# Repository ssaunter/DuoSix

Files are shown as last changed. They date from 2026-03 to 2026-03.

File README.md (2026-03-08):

# DuoSix
DuoSix is a 6-key, dual-encoder macropad powered by a Seeed Studio XIAO RP2040 and a PCF8574N IO Expander. 

Right now, the buttons are just bound to media controls, but I intend to update the code in the future to store "libraries" of key presets based on different apps or uses, which can be navigated and selected through the OLED and one of the encoders.

I made this project to learn how to use some new programs, while challenging myself to make something that I'll want to use for a long time. While I have experience in CAD and some of EDA in fusion, I had zero expereience in KiCad or Github before this project, so figuring everything out over about four days felt great.

---
**DuoSix Full Assembly**

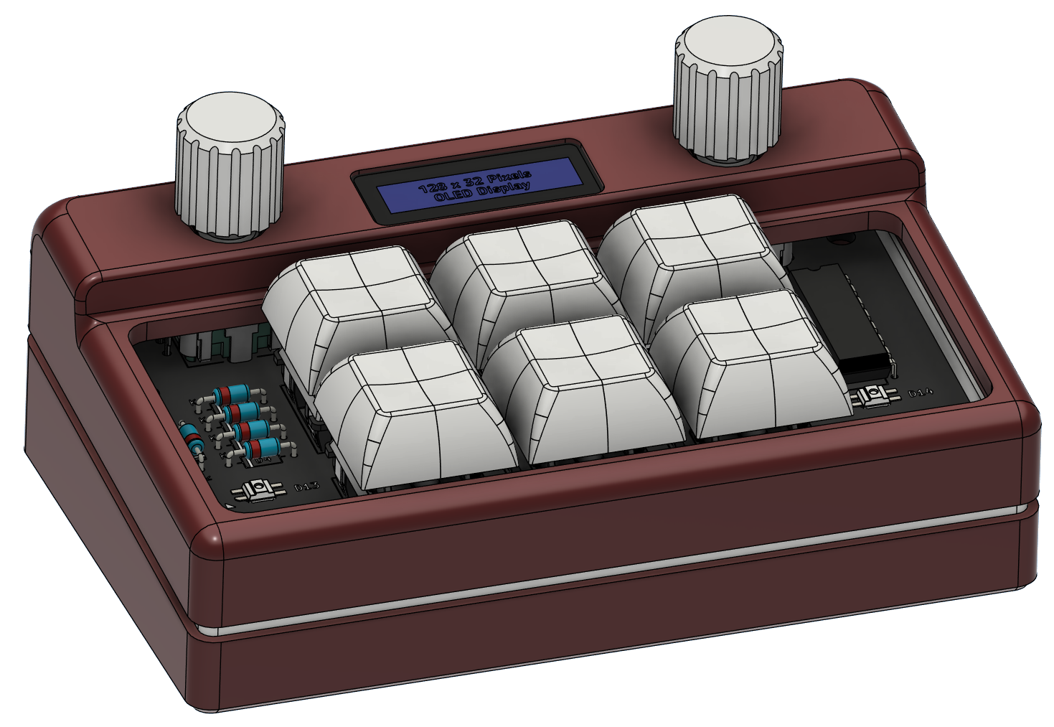
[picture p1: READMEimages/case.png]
Fully Assembly


---

**KiCad Schematic**

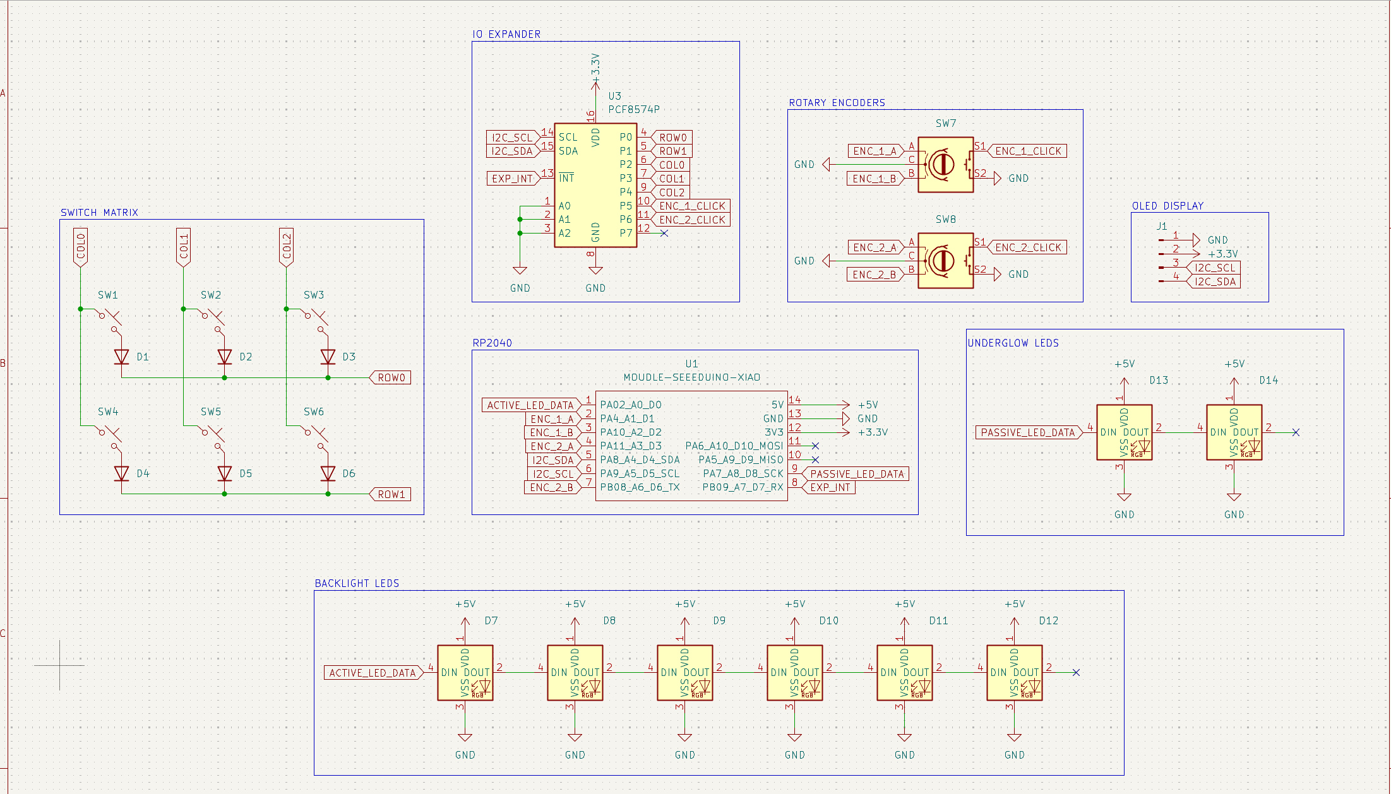
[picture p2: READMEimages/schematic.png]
Circuit schematic


---

**KiCad PCB Routing**

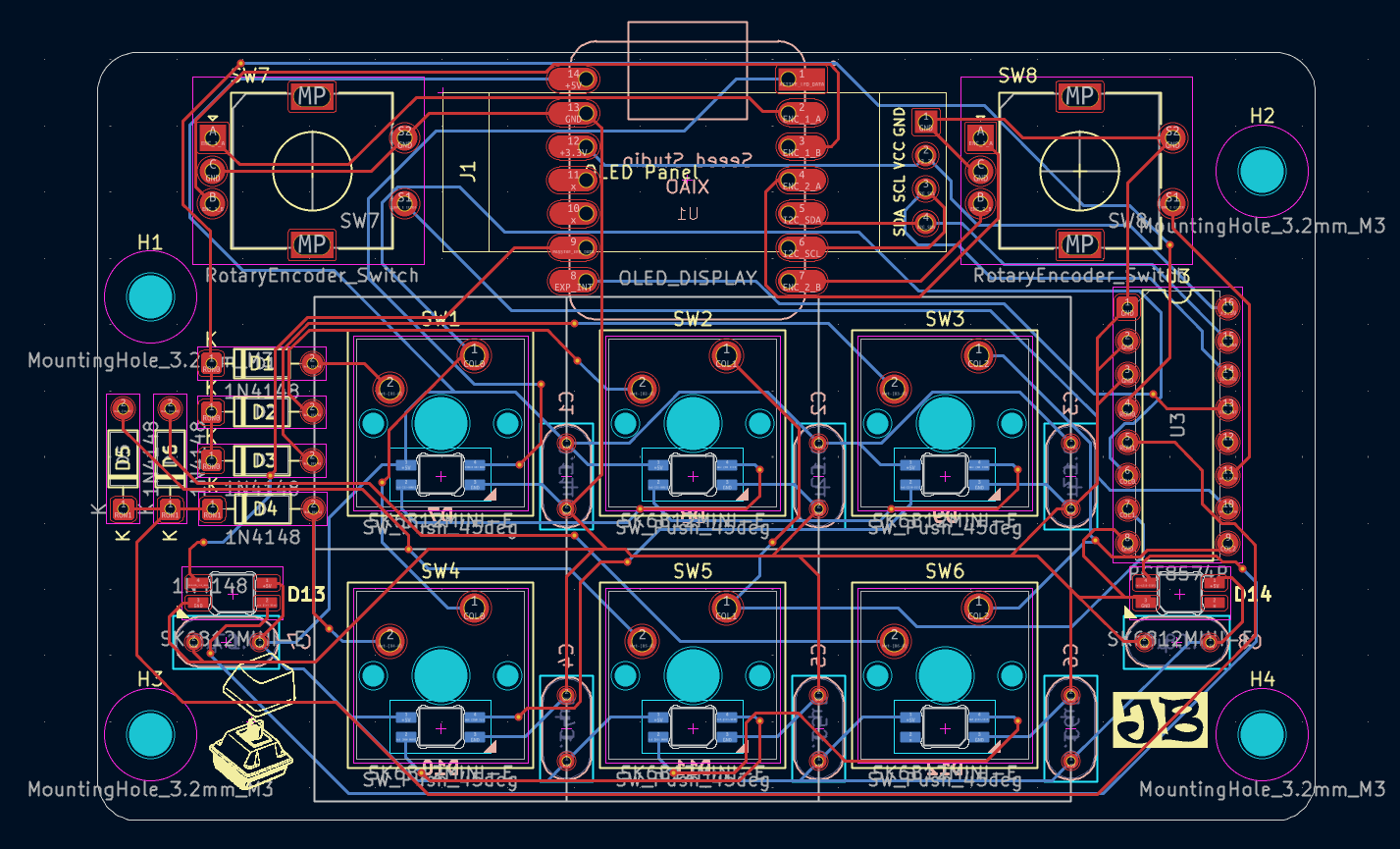
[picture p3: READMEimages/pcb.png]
PCB layout with IO expander


---

**Case and PCB Fitment**

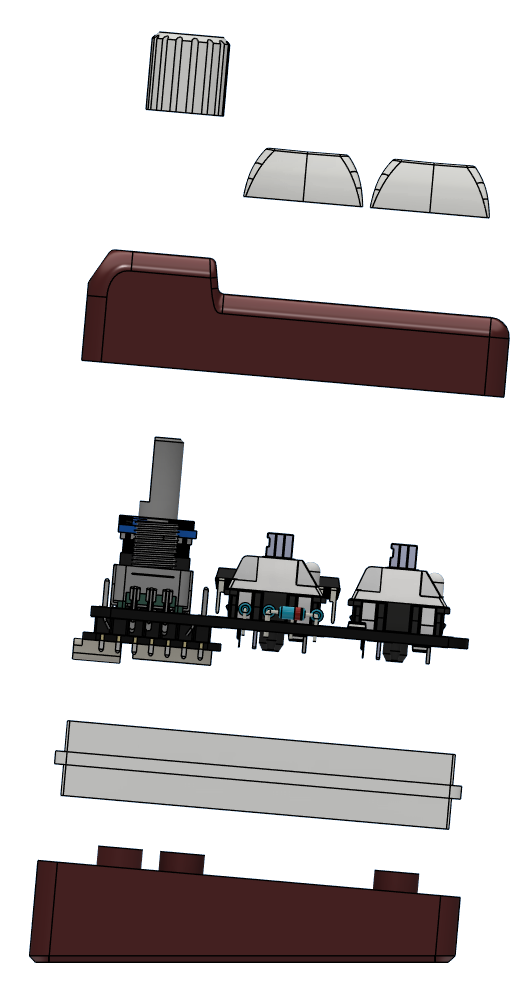
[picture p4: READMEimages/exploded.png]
3D printed case assembly


This design utilizes mostly press-fit connection. The PCB is mounted to the bottom case using M3x6 screws, and the diffusing ring is set in place around it, and in contact with the base. The diffusing ring is then slotted into the top case, holding the case together. I also made knobs to press-fit onto the rotary encoders.

---
### Bill of Materials (BOM)

**Included:**
* 1x Seeed Studio XIAO RP2040
* 6x MX-Style switches
* 6x DSA keycaps
* 2x EC11 rotary encoders
* 1x 0.91 inch OLED display
* 6x 1N4148 diodes
* 8x SK6812 MINI-E LEDs
* 4x M3x5mx4mm heatset inserts
* 3D Printed Case Components (Top, Bottom, Diffuser)

**Self Sourced:**
* 1x PCF8574N IO expander
* 1x 4 pin female socket (raises OLED up)
* 4x M3x6mm screws

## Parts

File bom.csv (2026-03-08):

Part | Quantity | Price | Link | Total
Seeed Studio XIAO RP2040 | 1 | $4.68 | https://www.digikey.com/en/products/detail/seeed-technology-co-ltd/102010428/14672129?gclsrc=aw.ds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 | $4.68
MX-Style Switches | 6 | $5.70 | https://www.digikey.com/en/products/detail/adafruit-industries-llc/5123/14617350?gclsrc=aw.ds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 | $10.38
Rotary Encoders (EC11) | 2 | $1.92 | https://www.digikey.com/en/products/detail/bourns-inc/PEC11R-4015F-N0024/4499636?gclsrc=aw.ds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 | $12.30
1N4148 Diodes | 5 | $0.50 | https://www.digikey.com/en/products/detail/onsemi/1N4148TA/1532747?gclsrc=aw.ds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 | $12.80
0.91 inch OLED | 1 | $7.88 | https://www.digikey.com/en/products/detail/midas-displays/MDOB128032GV-WI/25616500?gclsrc=aw.ds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 | $20.68
DSA Keycaps | 6 | $4.95 | https://www.digikey.com/en/products/detail/adafruit-industries-llc/5039/14313478?gclsrc=aw.ds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 | $25.63
SK6812 MINI-E LEDs | 8 | $2.95 | https://www.digikey.com/en/products/detail/adafruit-industries-llc/4960/14302512?gclsrc=aw.ds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 | $28.58
M3x5mx4mm heatset inserts | 4 | $4.99 | https://www.amazon.com/Aoserge-100Pcs-Brass-Heat-Inserts/dp/B0FM45X5TD | $33.57
PCF8574P IO Expander | 1 | $2.66 | https://www.digikey.com/short/qpvwbhz7 | $36.23
4 Pin Female Header | 1 | $0.37 | https://www.digikey.com/short/jwctq253 | $36.60

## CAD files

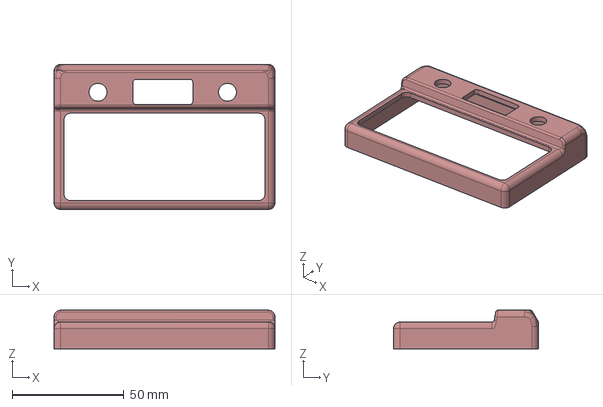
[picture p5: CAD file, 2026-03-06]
production/Top Case.step
99.0 x 65.0 x 17.3 mm

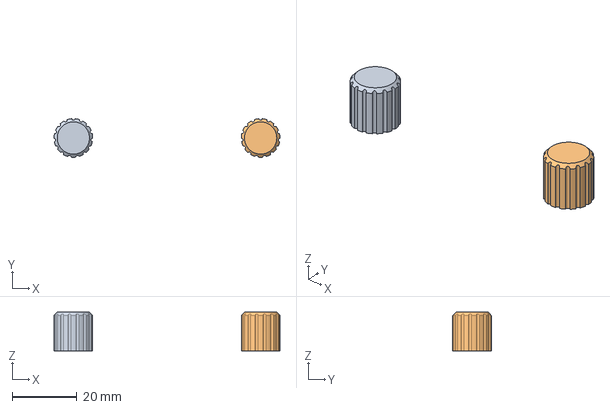
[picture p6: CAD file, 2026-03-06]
production/Knobs.step
70.0 x 12.0 x 12.0 mm

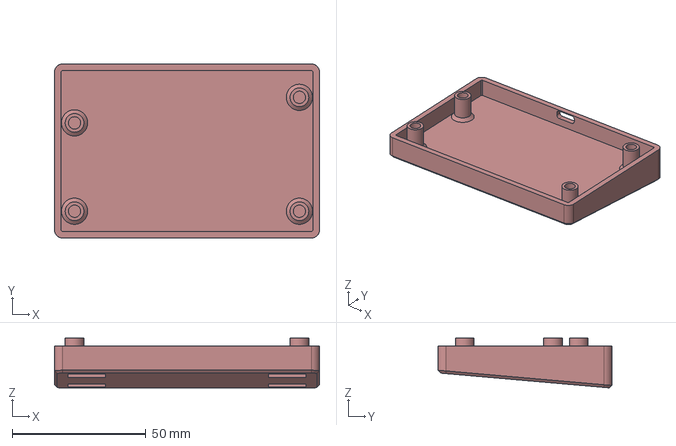
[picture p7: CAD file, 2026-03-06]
production/Bottom Case.step
99.0 x 65.0 x 18.6 mm

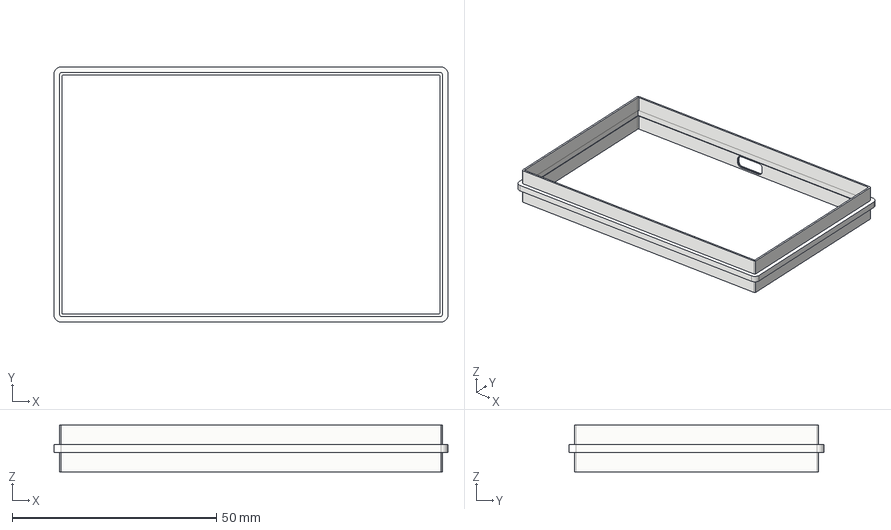
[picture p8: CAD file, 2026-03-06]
production/Diffusion Bar.step
96.5 x 62.5 x 11.5 mm

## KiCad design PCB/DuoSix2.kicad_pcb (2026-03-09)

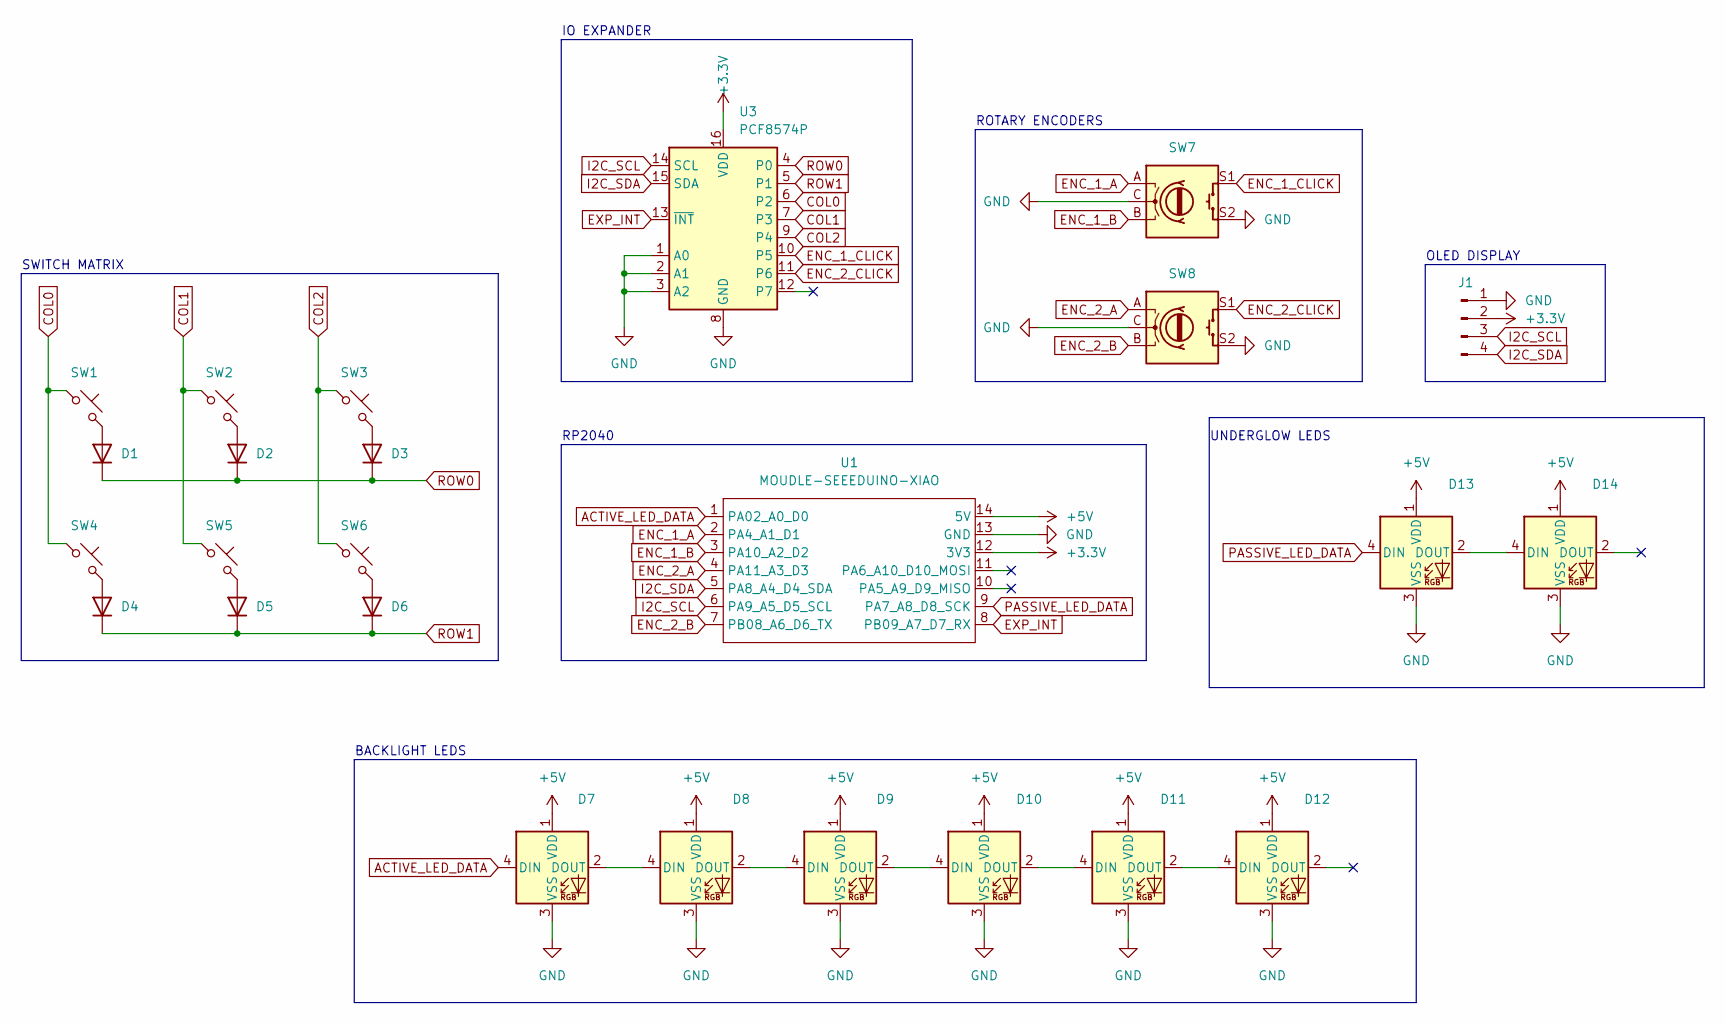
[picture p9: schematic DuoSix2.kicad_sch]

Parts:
D1, D2, D3, D4, D5, D6: 1N4148; D_DO-35_SOD27_P7.62mm_Horizontal
D7, D8, D9, D10, D11, D12, D13, D14: SK6812MINI-E; SK6812MINI-E_fixed
J1: OLED_DISPLAY; SSD1306-0.91-OLED-4pin-128x32
SW1, SW2, SW3, SW4, SW5, SW6: SW_Push_45deg; SW_Cherry_MX_1.00u_PCB
SW7, SW8: RotaryEncoder_Switch; RotaryEncoder_Alps_EC11E-Switch_Vertical_H20mm
U1: MOUDLE-SEEEDUINO-XIAO; XIAO-Generic-Hybrid-14P-2.54-21X17.8MM
U3: PCF8574P; DIP-16_W7.62mm

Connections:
+3.3V: J1.2, U1.12 (3V3), U3.16 (VDD)
+5V: D7.1 (VDD), D8.1 (VDD), D9.1 (VDD), D10.1 (VDD), D11.1 (VDD), D12.1 (VDD), D13.1 (VDD), D14.1 (VDD), U1.14 (5V)
ACTIVE_LED_DATA: D7.4 (DIN), U1.1 (PA02_A0_D0)
COL0: SW1.1, SW4.1, U3.6 (P2)
COL1: SW2.1, SW5.1, U3.7 (P3)
COL2: SW3.1, SW6.1, U3.9 (P4)
ENC_1_A: SW7.A, U1.2 (PA4_A1_D1)
ENC_1_B: SW7.B, U1.3 (PA10_A2_D2)
ENC_1_CLICK: SW7.S1, U3.10 (P5)
ENC_2_A: SW8.A, U1.4 (PA11_A3_D3)
ENC_2_B: SW8.B, U1.7 (PB08_A6_D6_TX)
ENC_2_CLICK: SW8.S1, U3.11 (P6)
EXP_INT: U1.8 (PB09_A7_D7_RX), U3.13 (~INT)
GND: D7.3 (VSS), D8.3 (VSS), D9.3 (VSS), D10.3 (VSS), D11.3 (VSS), D12.3 (VSS), D13.3 (VSS), D14.3 (VSS), J1.1, SW7.C, SW7.S2, SW8.C, SW8.S2, U1.13 (GND), U3.1 (A0), U3.2 (A1), U3.3 (A2), U3.8 (GND)
I2C_SCL: J1.3, U1.6 (PA9_A5_D5_SCL), U3.14 (SCL)
I2C_SDA: J1.4, U1.5 (PA8_A4_D4_SDA), U3.15 (SDA)
unnamed: D1.2 (A), SW1.2
unnamed: D2.2 (A), SW2.2
unnamed: D3.2 (A), SW3.2
unnamed: D4.2 (A), SW4.2
unnamed: D5.2 (A), SW5.2
unnamed: D6.2 (A), SW6.2
unnamed: D7.2 (DOUT), D8.4 (DIN)
unnamed: D8.2 (DOUT), D9.4 (DIN)
unnamed: D9.2 (DOUT), D10.4 (DIN)
unnamed: D10.2 (DOUT), D11.4 (DIN)
unnamed: D11.2 (DOUT), D12.4 (DIN)
unnamed: D13.2 (DOUT), D14.4 (DIN)
PASSIVE_LED_DATA: D13.4 (DIN), U1.9 (PA7_A8_D8_SCK)
ROW0: D1.1 (K), D2.1 (K), D3.1 (K), U3.4 (P0)
ROW1: D4.1 (K), D5.1 (K), D6.1 (K), U3.5 (P1)

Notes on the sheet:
IO EXPANDER
UNDERGLOW LEDS
SWITCH MATRIX
BACKLIGHT LEDS
OLED DISPLAY
RP2040
ROTARY ENCODERS

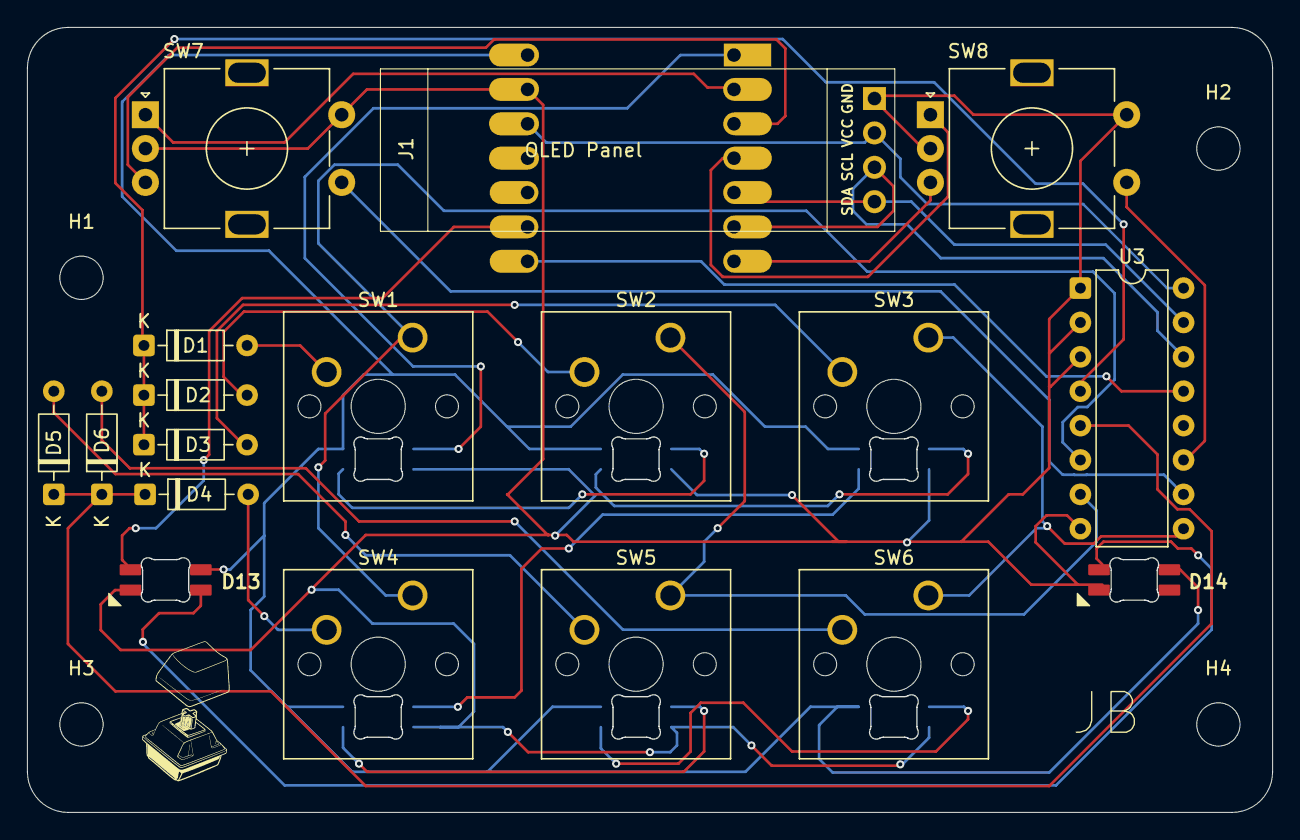
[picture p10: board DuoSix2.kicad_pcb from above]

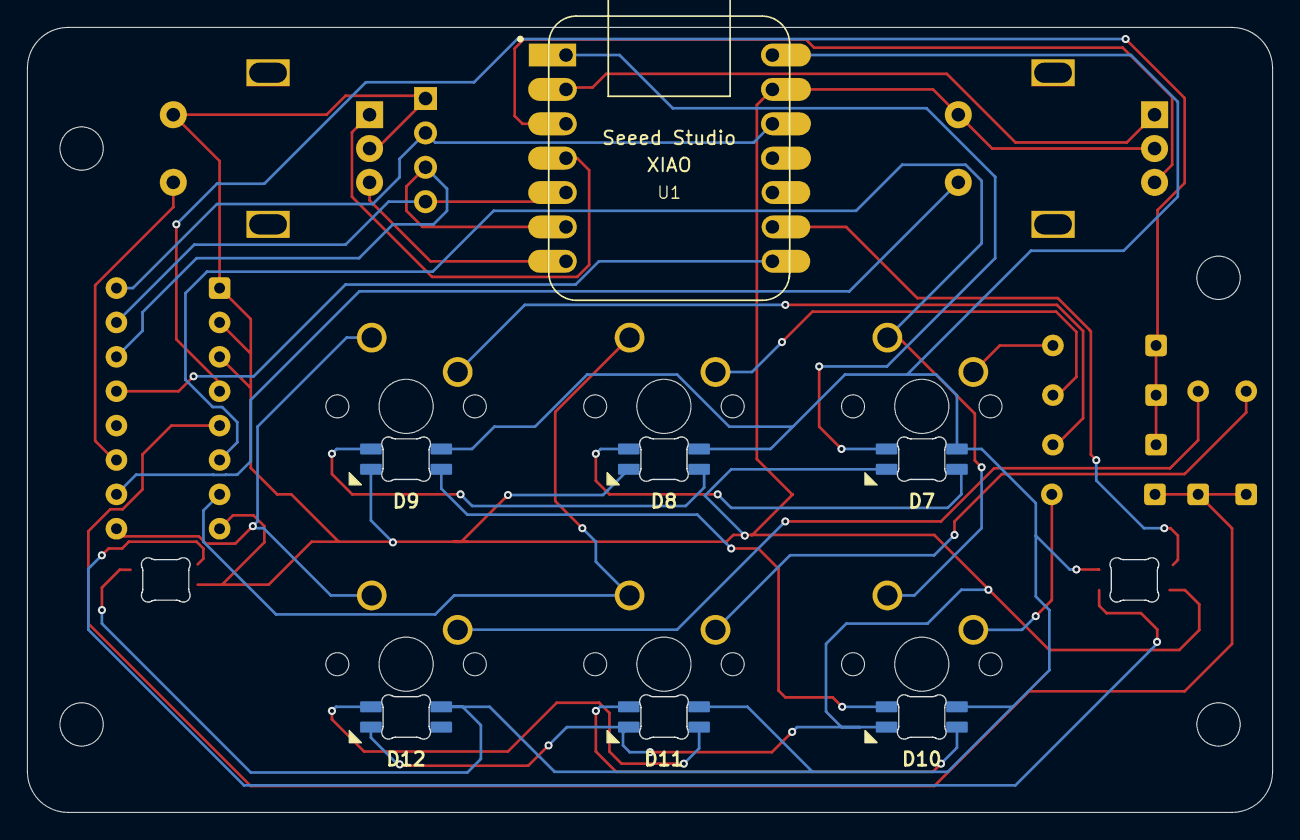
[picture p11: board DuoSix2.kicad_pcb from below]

Board: 2 copper layers, 92.0 x 58.0 mm, 29 parts (3 on the bottom side), 31 nets.

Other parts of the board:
H1, H2, H3, H4: MountingHole_3.2mm_M3

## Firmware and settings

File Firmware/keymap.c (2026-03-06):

// Copyright 2023 QMK
// SPDX-License-Identifier: GPL-2.0-or-later

#include QMK_KEYBOARD_H

// Buttons & Clicks
const uint16_t PROGMEM keymaps[][MATRIX_ROWS][MATRIX_COLS] = {
    [0] = LAYOUT(
        // Top Row of 3 Mechanical Switches
        KC_A,    KC_B,    KC_C, 
        
        // Bottom Row of 3 Mechanical Switches
        KC_D,    KC_E,    KC_F, 
        
        // The 2 Rotary Encoder Clicks (Left Click, Right Click)
        KC_MUTE, KC_MPLY  
    )
};

// Encoder Turns
bool encoder_update_user(uint8_t index, bool clockwise) {
    if (index == 0) { 
        // LEFT ENCODER (Index 0): Volume Control
        if (clockwise) {
            tap_code(KC_VOLU); // Volume Up
        } else {
            tap_code(KC_VOLD); // Volume Down
        }
    } else if (index == 1) { 
        // RIGHT ENCODER (Index 1): Mouse Scrolling
        if (clockwise) {
            tap_code16(MS_WHLD); // Scroll Down
        } else {
            tap_code16(MS_WHLU); // Scroll Up
        }
    }
    return false;
}

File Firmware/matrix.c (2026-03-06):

#include "matrix.h"
#include "quantum.h"
#include "i2c_master.h"

#define EXPANDER_ADDR 0x40
#define CUSTOM_I2C_TIMEOUT 100

matrix_row_t matrix[MATRIX_ROWS];

void matrix_init(void) {
    i2c_init();

    uint8_t init_state = 0xFF;
    i2c_transmit(EXPANDER_ADDR, &init_state, 1, CUSTOM_I2C_TIMEOUT);

    for (uint8_t i = 0; i < MATRIX_ROWS; i++) {
        matrix[i] = 0;
    }
}

uint8_t matrix_scan(void) {
    uint8_t cols[3] = {2, 3, 4};

    for (uint8_t col = 0; col < 3; col++) {
        // Pull current column LOW
        uint8_t col_state = ~(1 << cols[col]);
        i2c_transmit(EXPANDER_ADDR, &col_state, 1, CUSTOM_I2C_TIMEOUT);
        wait_us(30);

        // Read the expander state
        uint8_t port_state = 0xFF;
        i2c_receive(EXPANDER_ADDR, &port_state, 1, CUSTOM_I2C_TIMEOUT);

        // Standard Switches (Rows 0 and 1)
        for (uint8_t row = 0; row < 2; row++) {
            if (!(port_state & (1 << row))) {
                matrix[row] |= (1 << col); 
            } else {
                matrix[row] &= ~(1 << col); 
            }
        }

        // Encoder Clicks (Virtual Row 2)
        if (col == 0) {
            if (!(port_state & (1 << 5))) { matrix[2] |= (1 << 0); } else { matrix[2] &= ~(1 << 0); }
            if (!(port_state & (1 << 6))) { matrix[2] |= (1 << 1); } else { matrix[2] &= ~(1 << 1); }
        }
    }

    // Reset pins to HIGH
    uint8_t reset_state = 0xFF;
    i2c_transmit(EXPANDER_ADDR, &reset_state, 1, CUSTOM_I2C_TIMEOUT);

    return 1;
}

matrix_row_t matrix_get_row(uint8_t row) {
    return matrix[row];
}

void matrix_print(void) {
}

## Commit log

2026-03-06 Initial upload of DuoSix files
    [Bottom Case.step, Diffusion Bar.step, DuoSix.kicad_pcb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]
2026-03-06 Added BOM and F3Z cad file
    [bom.csv]
2026-03-08 Altered Design
    Removed decoupling capacitors and IC socket to reduce production cost
    [DuoSix2.kicad_pcb, DuoSix2.kicad_sch, bom.csv]
2026-03-08 Updated BOM
    Included prices and running total
    [bom.csv]
2026-03-09 Updated PCB
    Forgot some traces after changing model in last version
    [DuoSix2.kicad_pcb]
2026-03-10 Updated Images
    Changed images to reflect newest version of PCB & case
